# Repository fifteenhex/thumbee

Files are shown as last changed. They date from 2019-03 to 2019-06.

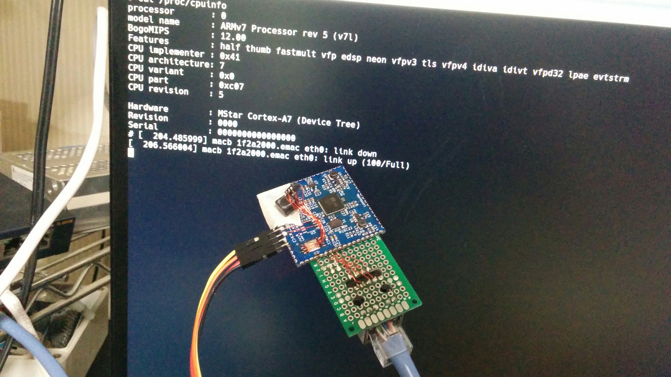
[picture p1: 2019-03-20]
photos/thumbee_firstboot.jpg

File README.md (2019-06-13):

This is dead. Look at https://github.com/fifteenhex/breadbee instead. It actually works. :D

# thumbee
MStar MSC313E SoC breakout

#rev0

Rough layout. Minimal decoupling caps because of limited space. Test to see if two layers works.
May move to some 0402 passives if not.

## bugs

Pinout foobar #1. USB ground isn't wired up because of a difference in the pin number of the symbol
and the footprint. Fixed by shorting the id pin to ground next to it.

Pinout foobar #2. avdd_nodie and dvdd_nodie are swapped. *edit* Maybe not. Seems like there is a datasheet
mistake. Pinout in the pin diagram is correct *edit* 

Pinout foobar #3. spi mosi and spi miso are swapped

Holtek USB->Serial chip is a piece of shit and can't handle lower baud rate data before data at the 
baud read the port was opened with.

1.8v supply is no good. The chip is very sensitive to the 1.8v rail dropping slightly (probably because
the DDR gets corrupted when it happens). On boot up the 1.8v drops for a split second and this makes
bootup hit or miss. Removing the 3.3va ldo and wiring 3.3va to 3.3v allows the input voltage to be lowered
to ~3.5v from the intended 5v and that makes the drop smaller.

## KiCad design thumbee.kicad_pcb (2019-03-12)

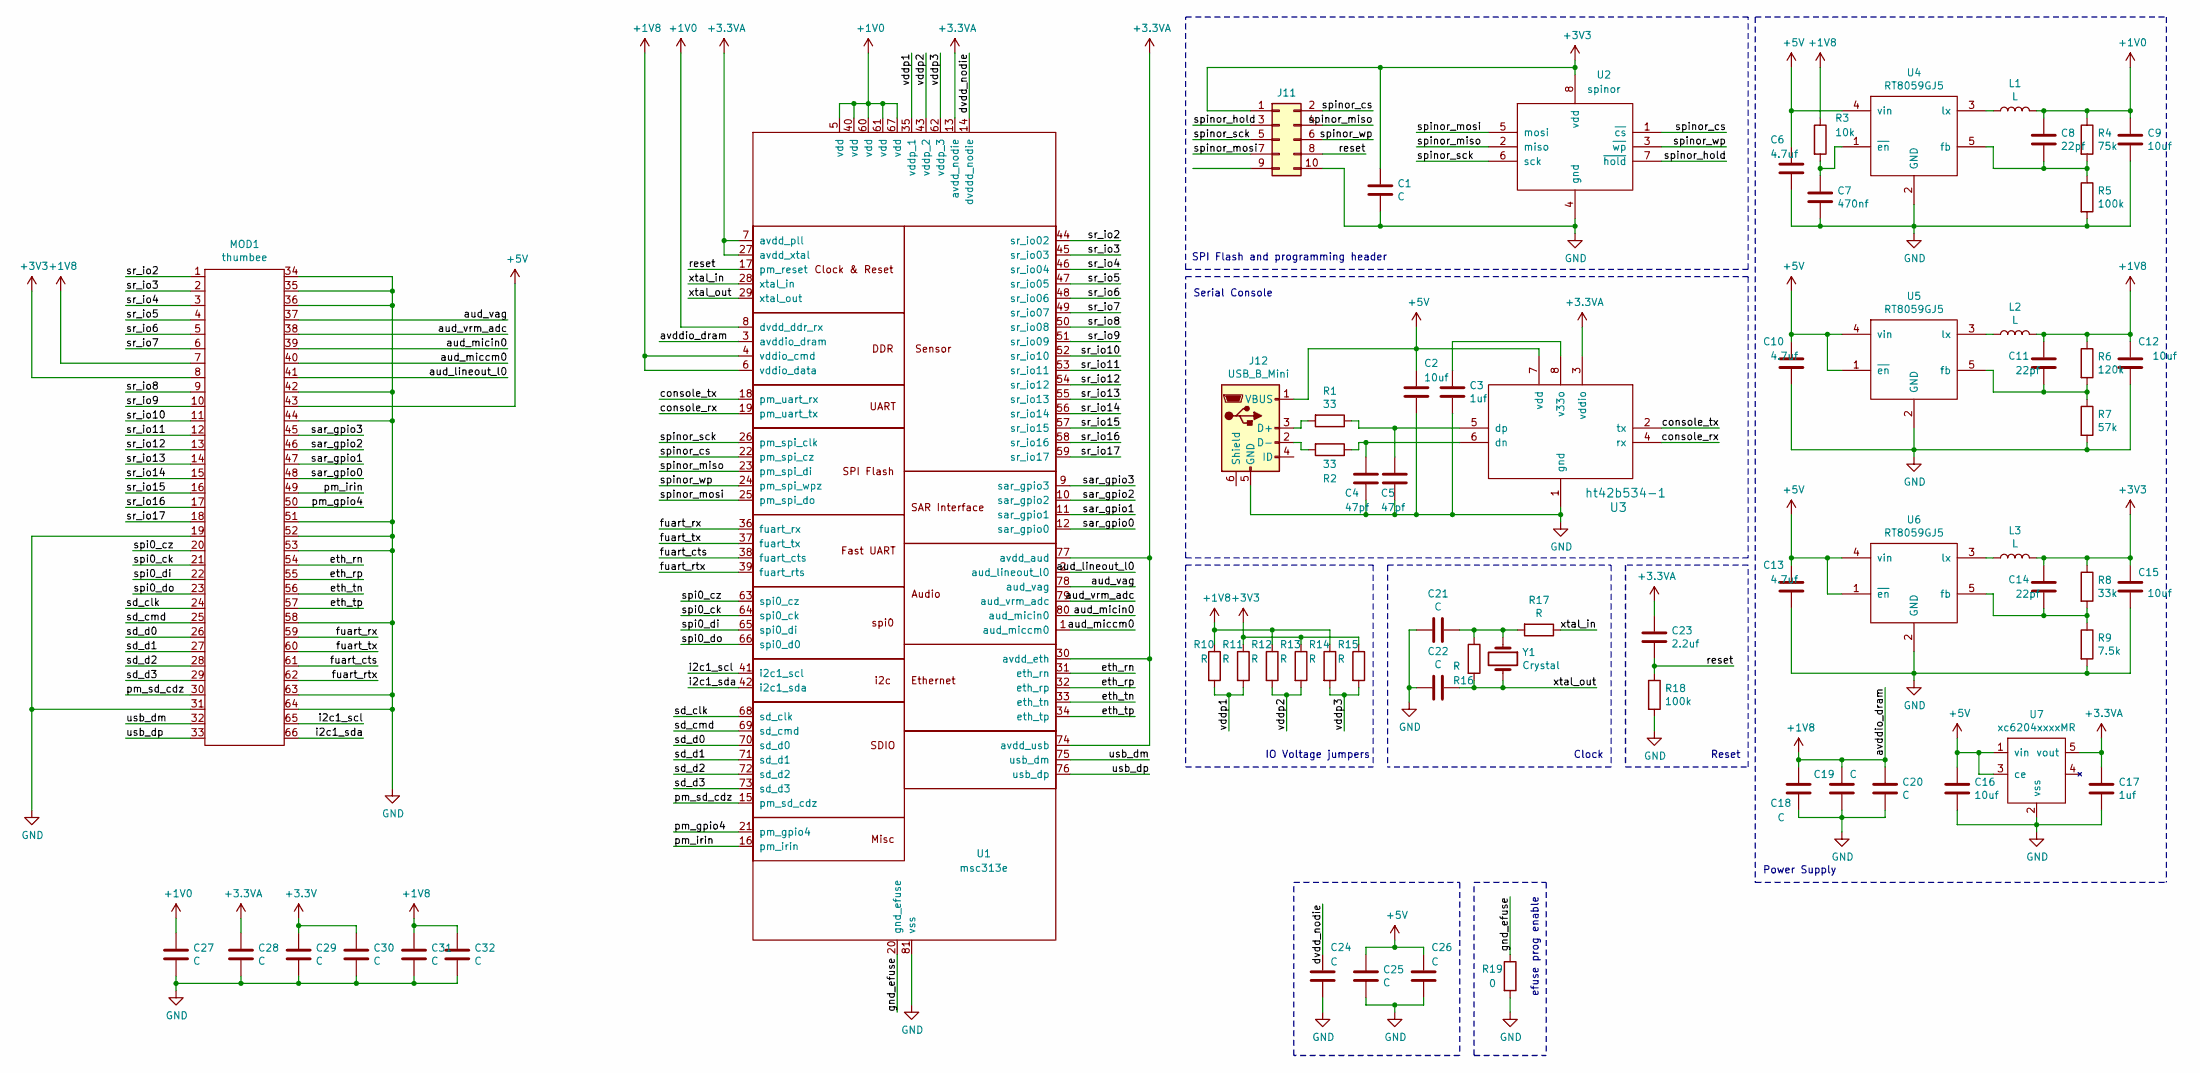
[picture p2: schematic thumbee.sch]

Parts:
C1, C18, C19, C20, C21, C22, C24, C25, C26, C27, C28, C29, C30, C31, C32: C; C_0603_1608Metric
C2, C9, C12, C15, C16: 10uf; C_0603_1608Metric
C3, C17: 1uf; C_0603_1608Metric
C4, C5: 47pf; C_0603_1608Metric
C6, C10, C13: 4.7uf; C_0603_1608Metric
C7: 470nf; C_0603_1608Metric
C8, C11, C14: 22pf; C_0603_1608Metric
C23: 2.2uf; C_0603_1608Metric
J11: Conn_02x05_Odd_Even; PinHeader_2x05_P1.00mm_Vertical_SMD
J12: USB_B_Mini; USB-MICRO-B
L1, L2, L3: L; CD32
MOD1: thumbee
R1, R2: 33; R_0603_1608Metric
R3: 10k; R_0603_1608Metric
R4: 75k; R_0603_1608Metric
R5, R18: 100k; R_0603_1608Metric
R6: 120k; R_0603_1608Metric
R7: 57k; R_0603_1608Metric
R8: 33k; R_0603_1608Metric
R9: 7.5k; R_0603_1608Metric
R10, R11, R12, R13, R14, R15, R16, R17: R; R_0603_1608Metric
R19: 0; R_0603_1608Metric
U1: msc313e; QFN-80_EP_8x8_Pitch0.35mm
U2: spinor; wson8-8x6mm
U3: ht42b534-1; SOIC-8_3.9x4.9mm_P1.27mm
U4, U5, U6: RT8059GJ5; TSOT-23-5
U7: xc6204xxxxMR; TSOT-23-5
Y1: Crystal; Crystal_SMD_5032-2Pin_5.0x3.2mm

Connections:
+1V0: C8.1, C9.1, C27.1, L1.2, R4.1, U1.5 (vdd), U1.8 (dvdd_ddr_rx), U1.40 (vdd), U1.60 (vdd), U1.61 (vdd), U1.67 (vdd)
+1V8: C11.1, C12.1, C18.1, C19.1, C20.1, C31.1, C32.1, L2.2, MOD1.7, R3.1, R6.1, R10.1, R12.1, R14.1, U1.3 (avddio_dram), U1.4 (vddio_cmd), U1.6 (vddio_data)
+3.3VA: C17.1, C23.1, C28.1, U1.7 (avdd_pll), U1.13 (avdd_nodie), U1.27 (avdd_xtal), U1.30 (avdd_eth), U1.74 (avdd_usb), U1.77 (avdd_aud), U3.3 (vddio), U7.5 (vout)
+5V: C2.1, C6.1, C10.1, C13.1, C16.1, C25.1, C26.1, J12.1 (VBUS), MOD1.43, U3.7 (vdd), U4.4 (vin), U5.1 (~en), U5.4 (vin), U6.1 (~en), U6.4 (vin), U7.1 (vin), U7.3 (ce)
/aud_lineout_l0: MOD1.41, U1.2 (aud_lineout_l0)
/aud_miccm0: MOD1.40, U1.1 (aud_miccm0)
/aud_micin0: MOD1.39, U1.80 (aud_micin0)
/aud_vag: MOD1.37, U1.78 (aud_vag)
/aud_vrm_adc: MOD1.38, U1.79 (aud_vrm_adc)
/console_rx: U1.19 (pm_uart_tx), U3.4 (rx)
/console_tx: U1.18 (pm_uart_rx), U3.2 (tx)
/dvdd_nodie: C24.2, U1.14 (dvddd_nodie)
/eth_rn: MOD1.54, U1.31 (eth_rn)
/eth_rp: MOD1.55, U1.32 (eth_rp)
/eth_tn: MOD1.56, U1.33 (eth_tn)
/eth_tp: MOD1.57, U1.34 (eth_tp)
/fuart_cts: MOD1.61, U1.38 (fuart_cts)
/fuart_rtx: MOD1.62, U1.39 (fuart_rts)
/fuart_rx: MOD1.59, U1.36 (fuart_rx)
/fuart_tx: MOD1.60, U1.37 (fuart_tx)
/gnd_efuse: R19.1, U1.20 (gnd_efuse)
/i2c1_scl: MOD1.65, U1.41 (i2c1_scl)
/i2c1_sda: MOD1.66, U1.42 (i2c1_sda)
/pm_gpio4: MOD1.50, U1.21 (pm_gpio4)
/pm_irin: MOD1.49, U1.16 (pm_irin)
/pm_sd_cdz: MOD1.30, U1.15 (pm_sd_cdz)
/reset: C23.2, J11.8, R18.1, U1.17 (pm_reset)
/sar_gpio0: MOD1.48, U1.12 (sar_gpio0)
/sar_gpio1: MOD1.47, U1.11 (sar_gpio1)
/sar_gpio2: MOD1.46, U1.10 (sar_gpio2)
/sar_gpio3: MOD1.45, U1.9 (sar_gpio3)
/sd_clk: MOD1.24, U1.68 (sd_clk)
/sd_cmd: MOD1.25, U1.69 (sd_cmd)
/sd_d0: MOD1.26, U1.70 (sd_d0)
/sd_d1: MOD1.27, U1.71 (sd_d1)
/sd_d2: MOD1.28, U1.72 (sd_d2)
/sd_d3: MOD1.29, U1.73 (sd_d3)
/spi0_ck: MOD1.21, U1.64 (spi0_ck)
/spi0_cz: MOD1.20, U1.63 (spi0_cz)
/spi0_di: MOD1.22, U1.65 (spi0_di)
/spi0_do: MOD1.23, U1.66 (spi0_d0)
/spinor_cs: J11.2, U1.22 (pm_spi_cz), U2.1 (~cs)
/spinor_hold: J11.3, U2.7 (~hold)
/spinor_miso: J11.4, U1.23 (pm_spi_di), U2.2 (miso)
/spinor_mosi: J11.7, U1.25 (pm_spi_do), U2.5 (mosi)
/spinor_sck: J11.5, U1.26 (pm_spi_clk), U2.6 (sck)
/spinor_wp: J11.6, U1.24 (pm_spi_wpz), U2.3 (~wp)
/sr_io2: MOD1.1, U1.44 (sr_io02)
/sr_io3: MOD1.2, U1.45 (sr_io03)
/sr_io4: MOD1.3, U1.46 (sr_io04)
/sr_io5: MOD1.4, U1.47 (sr_io05)
/sr_io6: MOD1.5, U1.48 (sr_io06)
/sr_io7: MOD1.6, U1.49 (sr_io07)
/sr_io8: MOD1.9, U1.50 (sr_io08)
/sr_io9: MOD1.10, U1.51 (sr_io09)
/sr_io10: MOD1.11, U1.52 (sr_io10)
/sr_io11: MOD1.12, U1.53 (sr_io11)
/sr_io12: MOD1.13, U1.54 (sr_io12)
/sr_io13: MOD1.14, U1.55 (sr_io13)
/sr_io14: MOD1.15, U1.56 (sr_io14)
/sr_io15: MOD1.16, U1.57 (sr_io15)
/sr_io16: MOD1.17, U1.58 (sr_io16)
/sr_io17: MOD1.18, U1.59 (sr_io17)
/usb_dm: MOD1.32, U1.75 (usb_dm)
/usb_dp: MOD1.33, U1.76 (usb_dp)
/vddp1: R10.2, R11.2, U1.35 (vddp_1)
/vddp2: R12.2, R13.2, U1.43 (vddp_2)
/vddp3: R14.2, R15.2, U1.62 (vddp_3)
/xtal_in: R17.1, U1.28 (xtal_in)
/xtal_out: C22.2, R16.2, U1.29 (xtal_out), Y1.2
GND: C1.2, C2.2, C3.2, C4.2, C5.2, C6.2, C7.2, C9.2, C10.2, C12.2, C13.2, C15.2, C16.2, C17.2, C18.2, C19.2, C20.2, C21.2, C22.1, C24.1, C25.2, C26.2, C27.2, C28.2, C29.2, C30.2, C31.2, C32.2, J11.10, J12.5 (GND), MOD1.19, MOD1.31, MOD1.34, MOD1.35, MOD1.36, MOD1.42, MOD1.44, MOD1.51, MOD1.52, MOD1.53, MOD1.58, MOD1.63, MOD1.64, R5.2, R7.2, R9.2, R18.2, R19.2, U1.81 (vss), U2.4 (gnd), U3.1 (gnd), U4.2 (GND), U5.2 (GND), U6.2 (GND), U7.2 (vss)
unnamed: C3.1, U3.8 (v33o)
unnamed: C4.1, R2.1, U3.6 (dn)
unnamed: C5.1, R1.1, U3.5 (dp)
unnamed: C7.1, R3.2, U4.1 (~en)
unnamed: C8.2, R4.2, R5.1, U4.5 (fb)
unnamed: C11.2, R6.2, R7.1, U5.5 (fb)
unnamed: C14.2, R8.2, R9.1, U6.5 (fb)
unnamed: C21.1, R16.1, R17.2, Y1.1
unnamed: J12.2 (D-), R2.2
unnamed: J12.3 (D+), R1.2
unnamed: L1.1, U4.3 (lx)
unnamed: L2.1, U5.3 (lx)
unnamed: L3.1, U6.3 (lx)

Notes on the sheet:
Power Supply
Reset
Serial Console
Clock
IO Voltage jumpers
efuse prog enable
SPI Flash and programming header

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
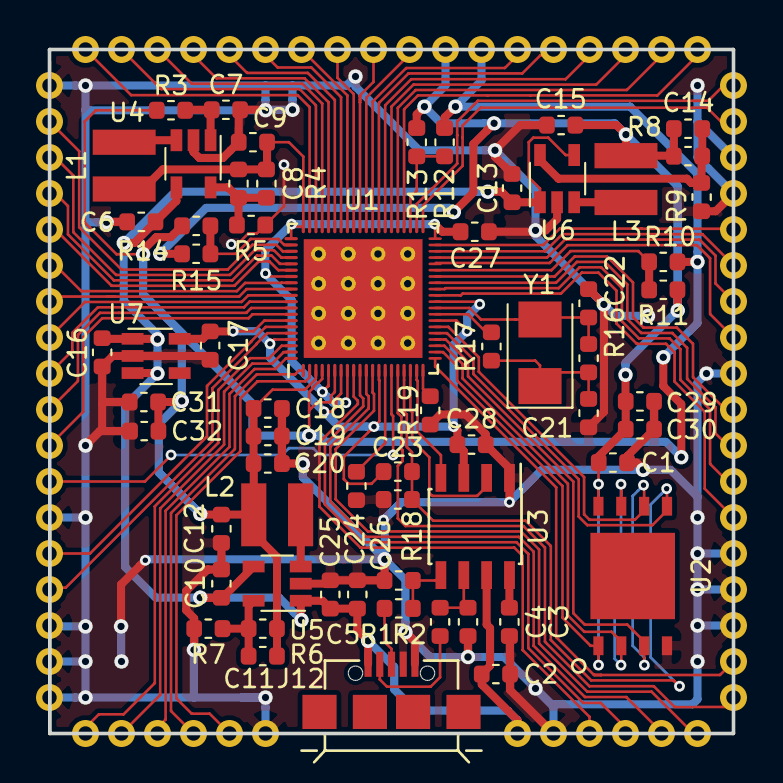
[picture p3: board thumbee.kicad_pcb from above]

Board: 2 copper layers, 38.0 x 38.0 mm, 65 parts (1 on the bottom side), 85 nets.

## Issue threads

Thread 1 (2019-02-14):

Datasheet for MSC313E

jeffreyantony, 2019-02-14:
Hi,

From where to get the datasheet for MSC313E ?

fifteenhex, 2019-02-26:
Hi,

Sorry for the delay. I don't seem to be getting notifications from github.

Other than the product brief that's in my other repo there isn't any data on the registers etc. I have the vendor kernel and uboot source uploaded here and I've managed to get a mainline kernel to boot and a bit of GPIO working.
There are some datasheets for other mstar SoCs on some Chinese sites that might have info that matches up with the MSC313E but I've been unable to download them so far.

jeffreyantony, 2019-02-26:
I was wondering how we will program this board without the datasheet. Any reasons for designing this board ? For what purpose will it be used ?

fifteenhex, 2019-02-27:
The lack of datasheet makes things a bit harder but having the vendor kernel and u-boot sources means that it's not totally impossible. I've mapped out most of the registers for the pin mux and GPIO based on the kernel code already.

The reasons for making this board:

- I have a personal mission to get a module with WiFi that runs Linux down to around $7 so there is a more secure option out there for projects that would otherwise use the ESP32. I've already done some boards for the Allwinner V3S and S3 which are about ~$10 with WiFi. The problem with those is that the V3S has a lot of pins and is easy to damage if you aren't careful. The S3 is a BGA part so it's not something you can hand solder. The MSC313E is the only Cortex-A7 chip I've ever seen in QFN. It's not widely available but the supplier I got mine from has them for ~$4 a piece. It's possible if this works out that they might be even cheaper when buying a hundred or a thousand at a time.

- At the moment I'm working with an IP camera board that has an MSC313E on it which limits the pins I can probe etc. This breakout board is initially to help with figuring out more of the registers, getting JTAG enabled etc.

- For fun. The MSC313E seems to have some weird stuff like a transparently encrypted data bus.

fifteenhex, 2019-03-06:
If you're still interested this PDF for another MStar chip documents a lot of the registers that are also present in the MSC313e: https://datasheetspdf.com/pdf-down/M/S/B/MSB2521_Mstar.pdf

Closed 2019-02-27.

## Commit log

2019-01-28 symbol and footprint
    [thumbee.kicad_pcb, thumbee.sch]
2019-02-05 Add remaining required components. Clean up schematic a bit.
    [thumbee.sch]
2019-02-06 Almost complete schematic
    [thumbee.sch]
2019-02-06 Fix schematic bugs. Assign footprints.
    [thumbee.kicad_pcb, thumbee.sch]
2019-02-08 QFN footprint fix up. Replace headers with a module footprint. Very rought parts layout and some routing.
    [thumbee.kicad_pcb, thumbee.sch]
2019-02-21 Rough all routed.
    [thumbee.kicad_pcb, thumbee.sch]
2019-02-22 Some clean up. Add some decoupling caps in the left over space.
    [thumbee.kicad_pcb, thumbee.sch]
2019-03-07 Document screwups so far
2019-03-10 Document more screw ups
2019-03-11 Add some component values. Fix avdd_nodie and dvdd_nodie.
    [thumbee.sch]
2019-03-11 Re-route avdd_nodie and dvdd_nodie
    [thumbee.kicad_pcb]
2019-03-12 Fix USB pinout
    [thumbee.kicad_pcb, thumbee.sch]
2019-03-14 Fix pm spi pin swap. Revert dvdd_nodie and avdd_nodie.
    [thumbee.sch]
2019-03-20 Update readme. Add photo of first working prototype
